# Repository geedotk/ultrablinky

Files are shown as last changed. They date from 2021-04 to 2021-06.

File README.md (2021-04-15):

# Ultrablinky Hardware

Ultrablinky is a strobelight/stroboscope that has multiple blink modes and can be triggered by different stimuli. If blinking an LED is the "Hello, world!" of the hardware/firmware world, Ultrablinky is the equivalent of shouting "HELLO, WORLD!"

## Use cases:
- Camera strobe, where a set number of flashes are triggered by motion
- Continuous flashing, because you know you want to pretend like you're at a rave
- Flashing synchronized with sound, because you still want to pretend you're at a rave, but you got tired of the asynchronous flashing
- Continuous flashing to freeze repetitive motion. Although it will look like the motion is stopped, don't be an idiot and stick your fingers in it, because it will hurt.
- Do other cool stuff that hasn't been thought of yet.

## Hardware
The "blinky" in the Ultrablinky is a 100W COB LED. This LED has forward voltage Vf of
30V-36V with a current of 3.5A.

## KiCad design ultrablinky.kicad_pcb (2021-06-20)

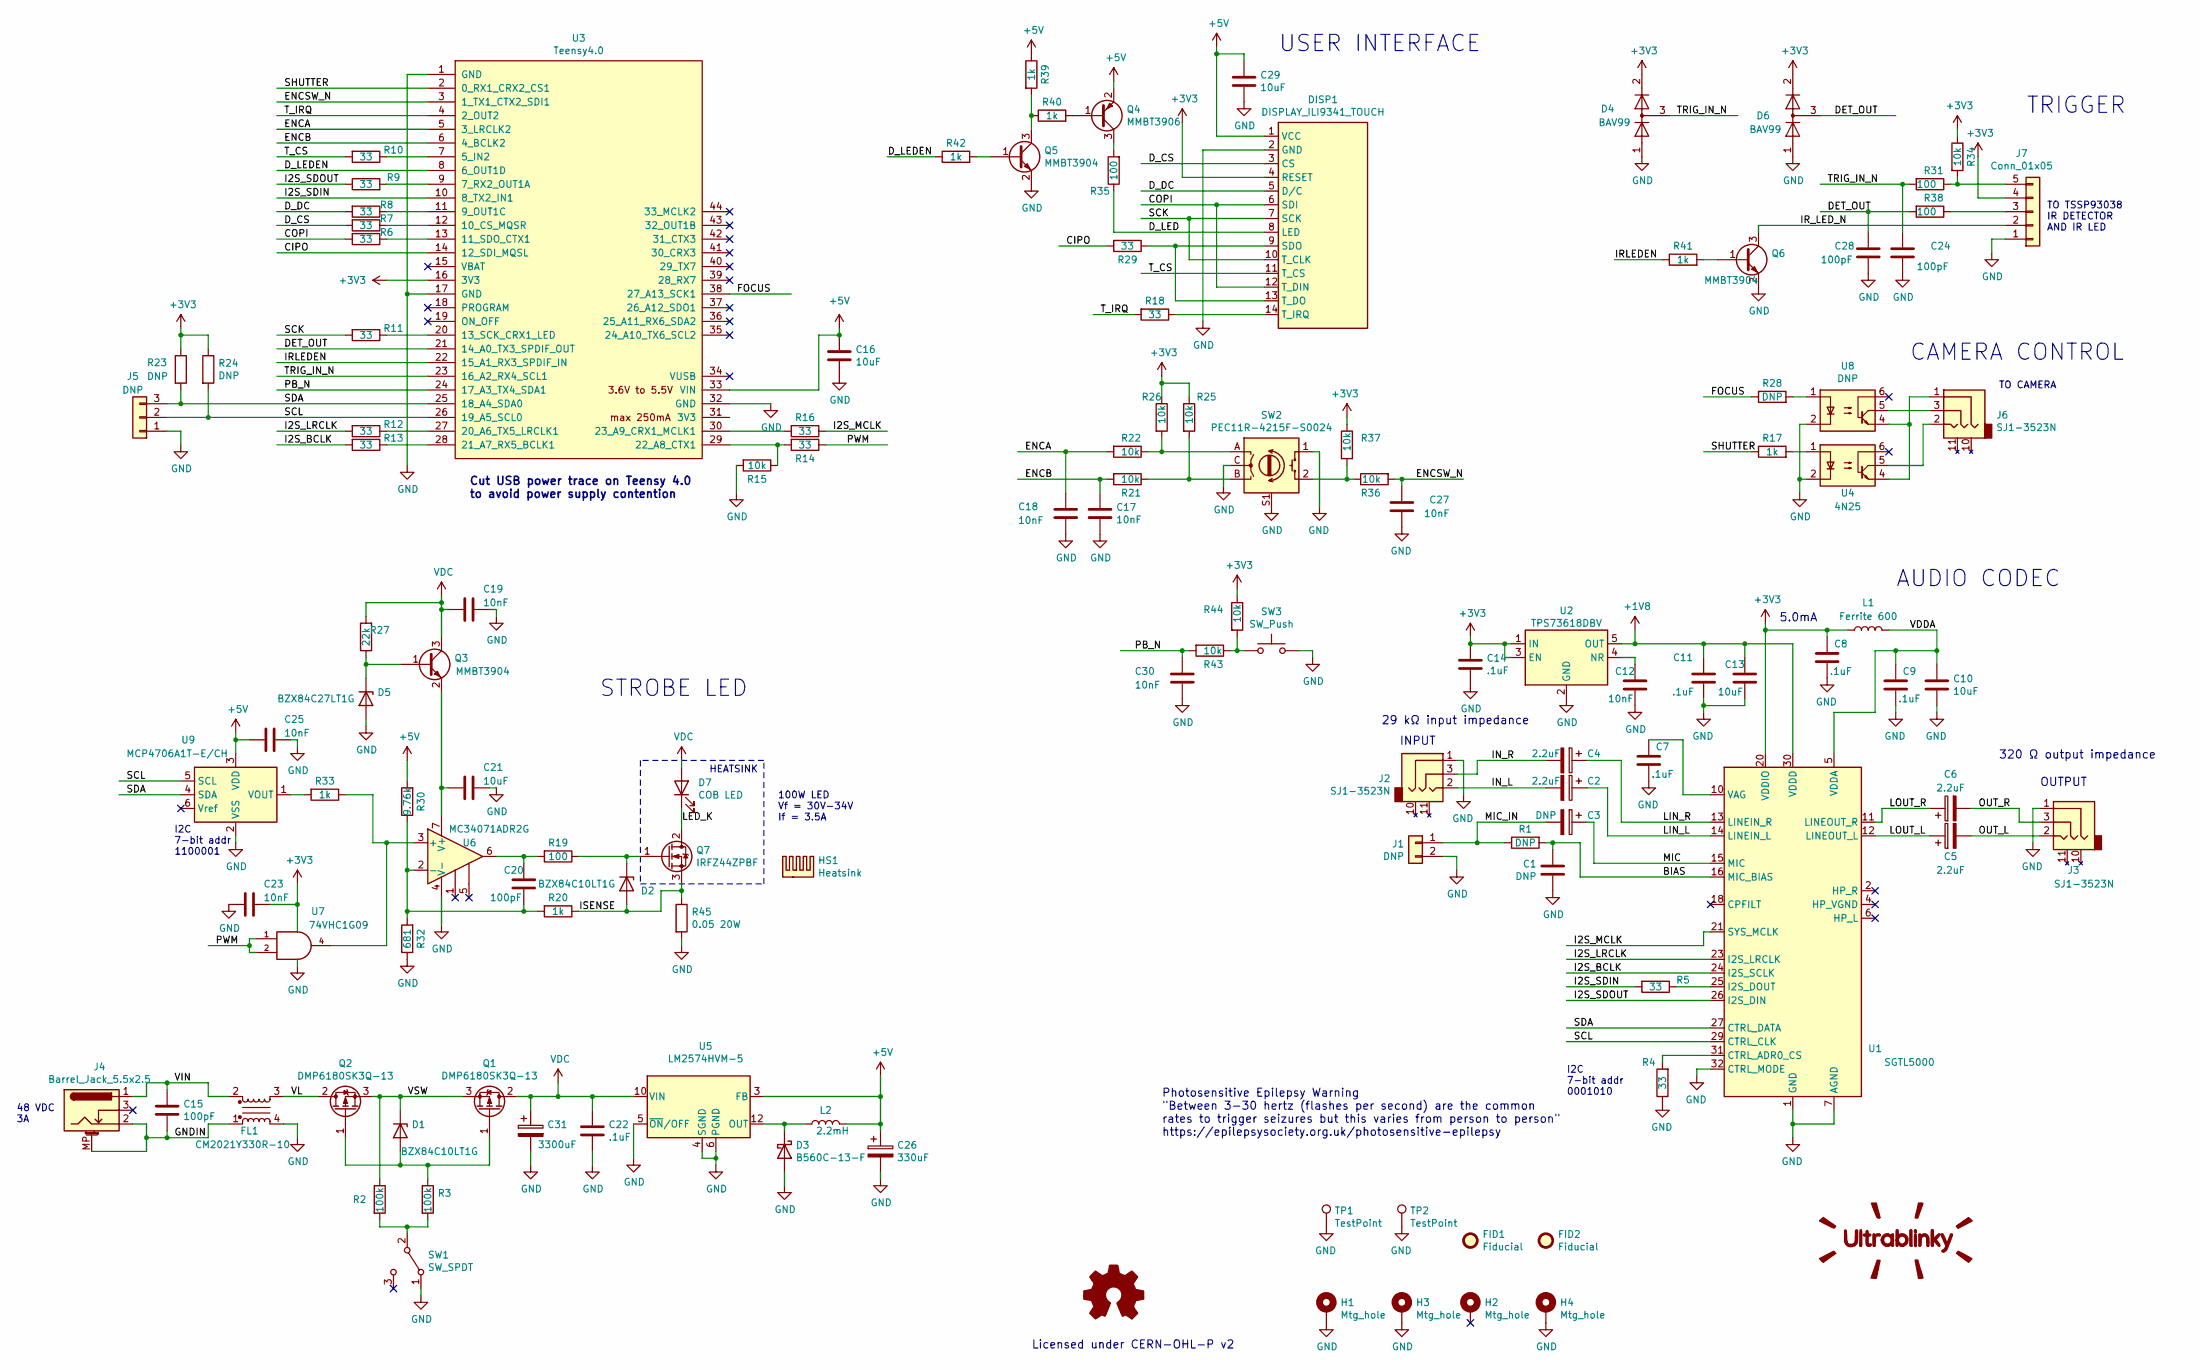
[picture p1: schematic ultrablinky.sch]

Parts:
C1: DNP; C_1206_3216Metric
C2, C4, C5, C6: 2.2uF; CP_Elec_4x5.7
C3: DNP; CP_Elec_4x5.7
C7, C8, C9, C11, C14, C22: .1uF; R_0805_2012Metric
C10, C13, C16, C21, C29: 10uF; C_1206_3216Metric
C12, C17, C18, C19, C23, C25, C27, C30: 10nF; C_0805_2012Metric
C15, C20, C24, C28: 100pF; C_0805_2012Metric
C26: 330uF; CP_Elec_8x10
C31: 3300uF; CP_Radial_L40.0mm_D20.0mm_P7.50mm_Horizontal
D1, D2: BZX84C10LT1G; D_SOT-23_ANK
D3: B560C-13-F; D_SMC
D4, D6: BAV99; SOT-23
D5: BZX84C27LT1G; D_SOT-23_ANK
D7: COB LED; LED_COB_100W
DISP1: DISPLAY_ILI9341_TOUCH
FID1, FID2: Fiducial; Fiducial_1mm_Mask2mm
FL1: CM2021Y330R-10; CM2021Y330R10
H1, H2, H3, H4: Mtg_hole; MountingHole_3.2mm_M3_DIN965_Pad
HS1: Heatsink; Heatsink_70x70mm_ATS-CPX070070025-136-C2-R0
J1: DNP; PinHeader_1x02_P2.54mm_Vertical
J2, J3, J6: SJ1-3523N; SJ13523N1_TRS_Jack
J4: Barrel_Jack_5.5x2.5; CUI_PJ-079BH
J5: DNP; PinHeader_1x03_P2.54mm_Vertical
J7: Conn_01x05; Molex_Mini-Fit_Jr_39-30-3055_1x05_P4.20mm_Horizontal
L1: Ferrite 600; L_0805_2012Metric
L2: 2.2mH; L_12x12mm_H10mm
LOGO1: Ultrablinky_logo; logo_ultrablinky
LOGO2: Logo_Open_Hardware_Small; OSHW-Logo2_9.8x8mm_SilkScreen
Q1, Q2: DMP6180SK3Q-13; TO-252-2
Q3, Q5, Q6: MMBT3904; SOT-23
Q4: MMBT3906; SOT-23
Q7: IRFZ44ZPBF; TO-220-3_Horizontal_TabDown
R1, R23, R24, R28: DNP; R_0805_2012Metric
R2, R3: 100k; R_0805_2012Metric
R4, R5, R6, R7, R8, R9, R10, R11, R12, R13, R14, R16, R18, R29: 33; R_0805_2012Metric
R15, R21, R22, R25, R26, R34, R36, R37, R43, R44: 10k; R_0805_2012Metric
R17, R20, R33, R39, R40, R41, R42: 1k; R_0805_2012Metric
R19, R31, R35, R38: 100; R_0805_2012Metric
R27: 22k; R_0805_2012Metric
R30: 9.76k; R_0805_2012Metric
R32: 681; R_0805_2012Metric
R45: 0.05 20W; TO-220-2_Horizontal_TabDown
SW1: SW_SPDT; SW_EG1213
SW2: PEC11R-4215F-S0024
SW3: SW_Push; SW_PUSH_6mm_H17mm
TP1, TP2: TestPoint; TestPoint_Keystone_5006
U1: SGTL5000; QFN-32-1EP_5x5mm_P0.5mm_EP3.6x3.6mm
U2: TPS73618DBV; SOT-23-5
U3: Teensy4.0; Teensy40
U4: 4N25; 4N25_OPTOCOUPLER_SMD
U5: LM2574HVM-5; SOIC-14W_7.5x9mm_P1.27mm
U6: MC34071ADR2G; SOIC-8_3.9x4.9mm_P1.27mm
U7: 74VHC1G09; SOT-353_SC-70-5_Handsoldering
U8: DNP; 4N25_OPTOCOUPLER_SMD
U9: MCP4706A1T-E/CH; SOT-23-6

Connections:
+1V8: C11.1, C13.1, U1.30 (VDDD), U2.5 (OUT)
+3V3: C8.1, C14.1, C23.1, D4.2 (A), D6.2 (A), DISP1.4 (RESET), J7.4, L1.1, R23.1, R24.1, R25.1, R26.1, R34.1, R37.1, R44.1, U1.20 (VDDIO), U2.1 (IN), U2.3 (EN), U3.16 (3V3), U7.5 (VCC)
+5V: C16.1, C25.2, C26.1, C29.1, DISP1.1 (VCC), L2.2, Q4.2 (E), R30.2, R39.1, U3.33 (VIN), U5.3 (FB), U9.3 (VDD)
/BIAS: C1.1, R1.2, U1.16 (MIC_BIAS)
/CIPO: R29.2, U3.14 (12_SDI_MQSL)
/COPI: DISP1.6 (SDI), DISP1.12 (T_DIN), R6.2
/DET_OUT: C28.1, D6.3 (K), R38.2, U3.21 (14_A0_TX3_SPDIF_OUT)
/D_CS: DISP1.3 (CS), R7.2
/D_DC: DISP1.5 (D/C), R8.2
/D_LED: DISP1.8 (LED), R35.1
/D_LEDEN: R42.1, U3.8 (6_OUT1D)
/ENCA: C18.1, R22.2, U3.5 (3_LRCLK2)
/ENCB: C17.1, R21.2, U3.6 (4_BCLK2)
/ENCSW_N: C27.1, R36.2, U3.3 (1_TX1_CTX2_SDI1)
/FOCUS: R28.1, U3.38 (27_A13_SCK1)
/GNDIN: C15.2, FL1.1, J4.2, J4.MP (MountPin)
/I2S_BCLK: R13.2, U1.24 (I2S_SCLK)
/I2S_LRCLK: R12.2, U1.23 (I2S_LRCLK)
/I2S_MCLK: R16.1, U1.21 (SYS_MCLK)
/I2S_SDIN: R5.2, U3.10 (8_TX2_IN1)
/I2S_SDOUT: R9.1, U1.26 (I2S_DIN)
/IN_L: C2.2, J2.2
/IN_R: C4.2, J2.3
/IRLEDEN: R41.1, U3.22 (15_A1_RX3_SPDIF_IN)
/IR_LED_N: J7.2, Q6.3 (C)
/ISENSE: D2.2 (A), Q7.3 (S), R20.1, R45.1
/LED_K: D7.1 (K), Q7.2 (D)
/LIN_L: C2.1, U1.14 (LINEIN_L)
/LIN_R: C4.1, U1.13 (LINEIN_R)
/LOUT_L: C5.1, U1.12 (LINEOUT_L)
/LOUT_R: C6.1, U1.11 (LINEOUT_R)
/MIC: C3.1, U1.15 (MIC)
/MIC_IN: C3.2, J1.1, R1.1
/OUT_L: C5.2, J3.2
/OUT_R: C6.2, J3.3
/PB_N: C30.1, R43.2, U3.24 (17_A3_TX4_SDA1)
/PWM: R14.1, U7.1, U7.2
/SCK: DISP1.7 (SCK), DISP1.10 (T_CLK), R11.2
/SCL: J5.2, R24.2, U1.29 (CTRL_CLK), U3.26 (19_A5_SCL0), U9.5 (SCL)
/SDA: J5.3, R23.2, U1.27 (CTRL_DATA), U3.25 (18_A4_SDA0), U9.4 (SDA)
/SHUTTER: R17.1, U3.2 (0_RX1_CRX2_CS1)
/TRIG_IN_N: C24.1, D4.3 (K), R31.2, U3.23 (16_A2_RX4_SCL1)
/T_CS: DISP1.11 (T_CS), R10.2
/T_IRQ: R18.2, U3.4 (2_OUT2)
/VDDA: C9.1, C10.1, L1.2, U1.5 (VDDA)
/VIN: C15.1, FL1.2, J4.1
/VL: FL1.3, Q2.2 (D)
/VSW: D1.1 (K), Q1.3 (S), Q2.3 (S), R2.1
GND: C1.2, C7.2, C8.2, C9.2, C10.2, C11.2, C12.2, C13.2, C14.2, C16.2, C17.2, C18.2, C19.1, C21.1, C22.2, C23.2, C24.2, C25.1, C26.2, C27.2, C28.2, C29.2, C30.2, C31.2, D3.2 (A), D4.1 (K), D5.2 (A), D6.1 (K), DISP1.2 (GND), FL1.4, H1.1, H3.1, H4.1, J1.2, J2.1, J3.1, J5.1, J7.1, Q5.2 (E), Q6.2 (E), R4.1, R15.2, R32.1, R45.2, SW1.1 (A), SW2.1, SW2.C, SW2.S1, SW2.S2, SW3.2, TP1.1, TP2.1, U1.1 (GND), U1.3 (GND), U1.7 (AGND), U1.32 (CTRL_MODE), U1.33 (GND), U2.2 (GND), U3.1 (GND), U3.17 (GND), U3.32 (GND), U4.2, U5.1 (NC), U5.2 (NC), U5.4 (SGND), U5.5 (~ON~/OFF), U5.6 (PGND), U5.7 (NC), U5.8 (NC), U5.9 (NC), U5.11 (NC), U5.13 (NC), U5.14 (NC), U6.4 (V-), U7.3 (GND), U8.2, U9.2 (VSS)
unnamed: C7.1, U1.10 (VAG)
unnamed: C12.1, U2.4 (NR)
unnamed: C20.1, R19.2, U6.6
unnamed: C20.2, R20.2, R30.1, R32.2, U6.2 (-)
unnamed: C21.2, Q3.2 (E), U6.7 (V+)
unnamed: D1.2 (A), Q1.1 (G), Q2.1 (G), R3.1
unnamed: D2.1 (K), Q7.1 (G), R19.1
unnamed: D3.1 (K), L2.1, U5.12 (OUT)
unnamed: D5.1 (K), Q3.1 (B), R27.1
unnamed: DISP1.9 (SDO), DISP1.13 (T_DO), R29.1
unnamed: DISP1.14 (T_IRQ), R18.1
unnamed: J6.1, U4.4, U8.4
unnamed: J6.2, U4.5
unnamed: J6.3, U8.5
unnamed: J7.3, R38.1
unnamed: J7.5, R31.1, R34.2
unnamed: Q4.1 (B), R40.2
unnamed: Q4.3 (C), R35.2
unnamed: Q5.1 (B), R42.2
unnamed: Q5.3 (C), R39.2, R40.1
unnamed: Q6.1 (B), R41.2
unnamed: R2.2, R3.2, SW1.2 (B)
unnamed: R4.2, U1.31 (CTRL_ADR0_CS)
unnamed: R5.1, U1.25 (I2S_DOUT)
unnamed: R6.1, U3.13 (11_SDO_CTX1)
unnamed: R7.1, U3.12 (10_CS_MQSR)
unnamed: R8.1, U3.11 (9_OUT1C)
unnamed: R9.2, U3.9 (7_RX2_OUT1A)
unnamed: R10.1, U3.7 (5_IN2)
unnamed: R11.1, U3.20 (13_SCK_CRX1_LED)
unnamed: R12.1, U3.27 (20_A6_TX5_LRCLK1)
unnamed: R13.1, U3.28 (21_A7_RX5_BCLK1)
unnamed: R14.2, R15.1, U3.29 (22_A8_CTX1)
unnamed: R16.2, U3.30 (23_A9_CRX1_MCLK1)
unnamed: R17.2, U4.1
unnamed: R21.1, R25.2, SW2.B
unnamed: R22.1, R26.2, SW2.A
unnamed: R28.2, U8.1
unnamed: R33.1, U6.3 (+), U7.4
unnamed: R33.2, U9.1 (VOUT)
unnamed: R36.1, R37.2, SW2.2
unnamed: R43.1, R44.2, SW3.1
VDC: C19.2, C22.1, C31.1, D7.2 (A), Q1.2 (D), Q3.3 (C), R27.2, U5.10 (VIN)

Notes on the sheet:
HEATSINK
100W LED Vf = 30V-34V If = 3.5A
I2C 7-bit addr 1100001
48 VDC 3A
Photosensitive Epilepsy Warning "Between 3-30 hertz (flashes per second) are the common rates to trigger seizures but this varies from person to person" https://epilepsysociety.org.uk/photosensitive-epilepsy
Licensed under CERN-OHL-P v2
Cut USB power trace on Teensy 4.0 to avoid power supply contention
TO CAMERA
TO TSSP93038 IR DETECTOR AND IR LED
INPUT
OUTPUT
AUDIO CODEC
29 kΩ input impedance
320 Ω output impedance
I2C 7-bit addr 0001010
USER INTERFACE
STROBE LED
TRIGGER
CAMERA CONTROL
5.0mA

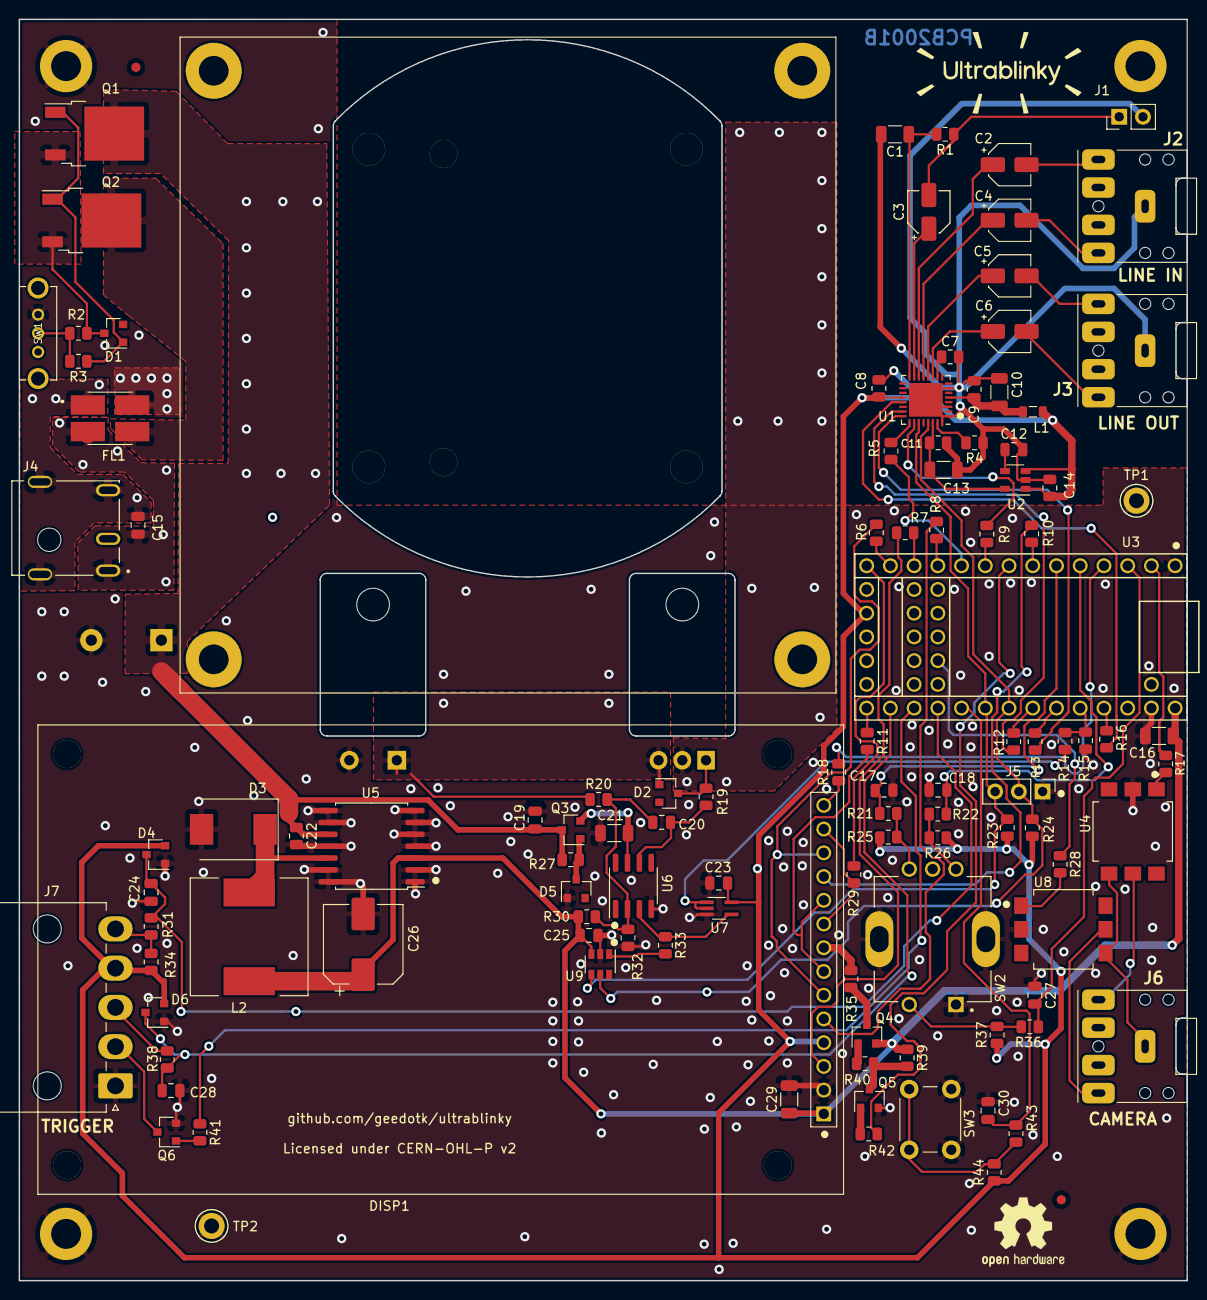
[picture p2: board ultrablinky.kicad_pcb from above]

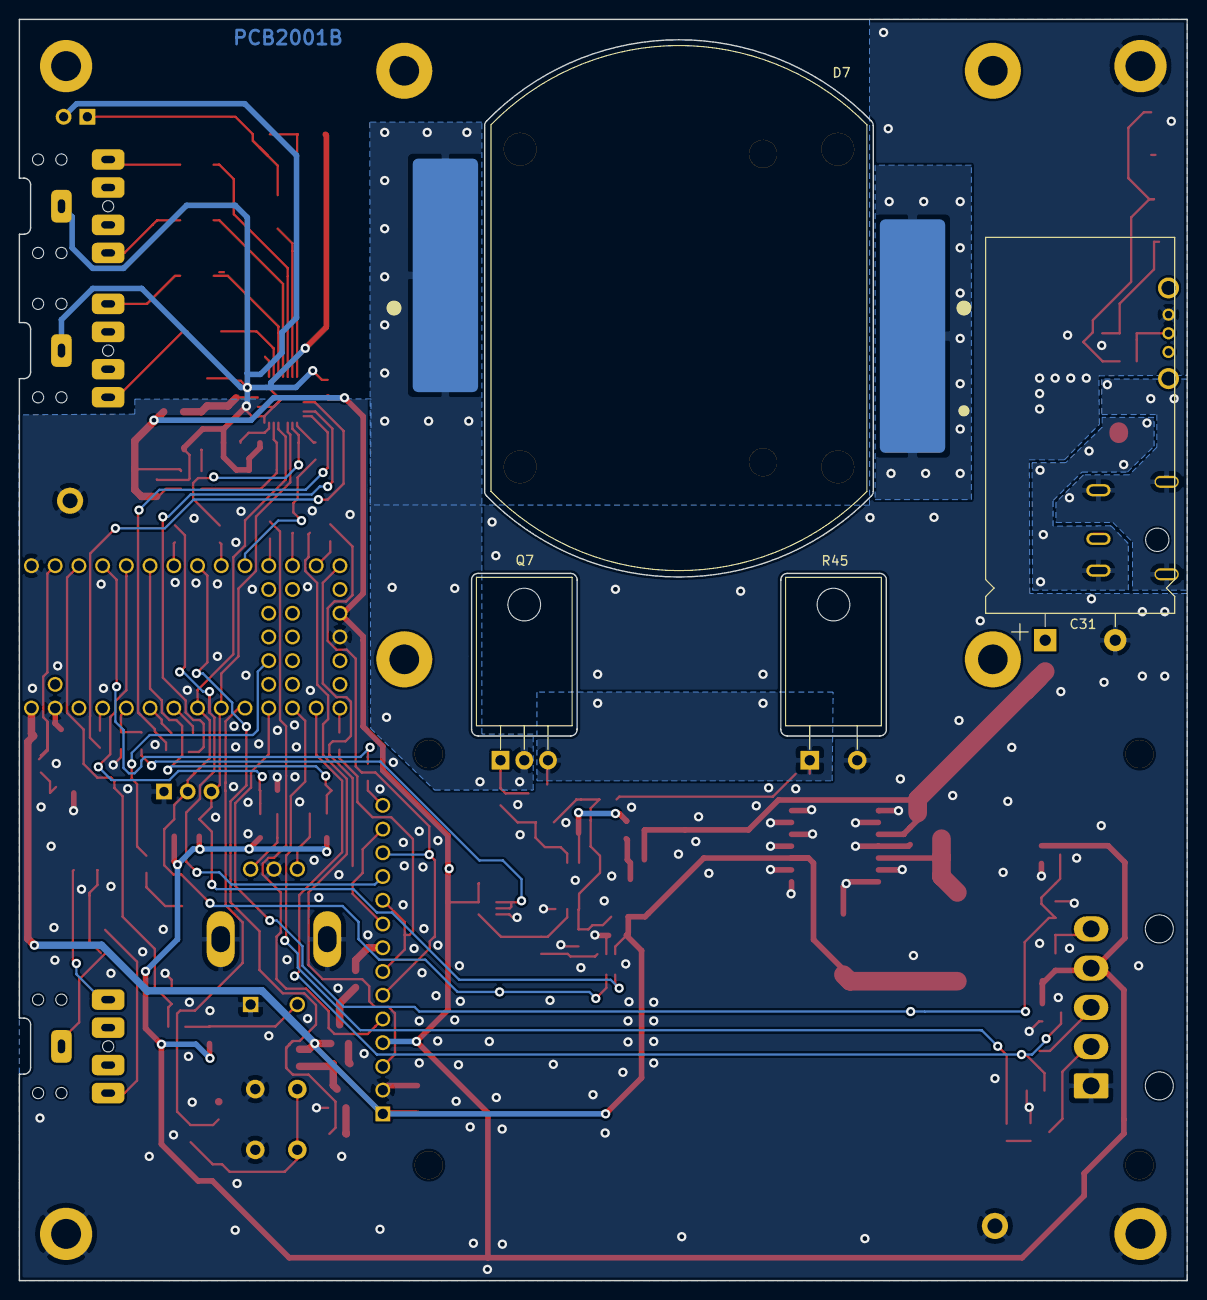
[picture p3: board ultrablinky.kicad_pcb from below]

Board: 2 copper layers, 125.0 x 135.0 mm, 124 parts (4 on the bottom side), 92 nets.

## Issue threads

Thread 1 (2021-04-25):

Open Hardware logo is illegible

geedotk, 2021-04-25:
Need to use a larger logo, or at least one with a larger font

geedotk, 2021-06-16:
Fixed on PCB2001B

Closed 2021-06-16.

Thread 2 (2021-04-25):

Q7 and R43 references overlap with board edge cut

geedotk, 2021-04-25:
The bottom part of the Q7 and R43 references are cut off by the board edge cut. Need to move them higher

geedotk, 2021-06-16:
Fixed on PCB2001B

Closed 2021-06-16.

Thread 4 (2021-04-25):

Add more prominent pin 1 markers

geedotk, 2021-04-25:
The KiCad pin 1 markers for ICs are very difficult to see. Add something (dots?) that is easier to see for hand assembly.

geedotk, 2021-07-06:
Fixed on rev B PCB

Closed 2021-07-06.

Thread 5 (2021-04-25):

Optocoupler footprint is too narrow

geedotk, 2021-04-25:
The footprint for optocouplers U4 and U7 are so narrow that the pins go all the way to edge of the pad, leaving much pad underneath the part

geedotk, 2021-06-19:
Corrected the footprint to match the suggested pattern in the data sheet

Closed 2021-06-19.

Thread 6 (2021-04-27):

Through-holes for display (DISP1) connector are too small

geedotk, 2021-04-27:
The holes on the 1x14 connector are only 0.7mm, when they should be at least 1mm. Now they are too small for a 0.025" square post. Make these larger on the next rev

geedotk, 2021-06-19:
Changed hole size to be 1.1mm

Closed 2021-06-19.

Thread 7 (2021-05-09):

I2S SDIN and SDOUT going to wrong pins of Teensy

geedotk, 2021-05-09:
I2S SDIN and SDOUT currently go to pins 7 and 8 of the Teensy footprint, when they should go to Arduino DIO pins 7 and 8 instead, which are actually pins 9 and 10 of the Teensy footprint.

geedotk, 2021-05-12:
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
Pin 7 should be swapped with pin 10. Pin 8 should be swapped with pin 9.

geedotk, 2021-06-19:
Corrected traces on rev B PCB

Closed 2021-06-19.

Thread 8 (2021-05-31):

Strobe LED stays on dimly when PWM should shut it off completely

geedotk, 2021-05-31:
The non-inverting input of the U6 op amp goes down to about 13mV when the PWM signal is high, but that's still enough for about 26mA of current to go through the COB LED.

One possible solution is to pull up the inverting input of the op amp so that it is certain to be higher than the lowest voltage on the non-inverting input.

geedotk, 2021-05-31:
Adding a 22k resistor from 5V to the inverting input of the op amp allows the LED to be turned off completely. This will be fixed in the next revision of the PCB

geedotk, 2021-06-19:
Added pull-up resistor to rev B PCB

Closed 2021-06-19.

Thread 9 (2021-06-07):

High current can cause current-sense resistor voltage more than 5V

geedotk, 2021-06-07:
The COB LED needs to be overdriven in order to be bright enough with short pulse widths. However, the 0.5-ohm resistor will have a voltage more than 5V when the current is only 10A. The current sense resistor needs to be smaller.

geedotk, 2021-06-19:
Changed resistor to 0.05 ohms on rev B PCB

Closed 2021-06-19.

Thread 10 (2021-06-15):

Disabled PWM timer defaults to the strobe LED being on

geedotk, 2021-06-15:
When the Teensy PWM timer is disabled, the output is low. Since the output goes through an NPN transistor to pull the DAC low, this means the DAC output will be high. The logic needs another inversion so that when the PWM timer is disabled low, the DAC will also be pulled low.

geedotk, 2021-06-19:
Changed NPN transistor to 74VHC1G09 gate so that no inversion takes place on rev B PCB

Closed 2021-06-19.

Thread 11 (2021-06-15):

High-current drive of the strobe LED pulls supply down

geedotk, 2021-06-15:
The strobe LED will often need much more than the 6A that the power supply can source. More capacitance will be needed to allow this to happen.

geedotk, 2021-06-19:
Added 3300uF capacitor on rev B PCB

Closed 2021-06-19.

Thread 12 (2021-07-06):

Inrush current damages the power switch MOSFET

geedotk, 2021-07-06:
On the rev B PCB, a 3300uF capacitor was added to the power rail. When the power switch is turned on, the inrush current to charge that capacitor was measured to be up to 120A for about 0.5ms, which destroys the Q1 MOSFET. The maximum continuous current for that MOSFET is 14A.

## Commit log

2021-04-15 First version of Ultrablinky strobe
    KiCad schematics and PCB (PCB2001A) for Ultrablinky strobe.
    [ultrablinky-B_Cu.gbr, ultrablinky-B_Fab.gbr, ultrablinky-B_Mask.gbr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]
2021-04-26 Changed C12 from 50V to 100V
    This was changed so that the same 10nF cap could be used in all
    locations instead of having two different 10nF parts
    [ultrablinky.sch]
2021-05-26 Corrected the I2S_SDIN and I2S_SDOUT pins
    Previously, the I2S_SDIN and I2S_SDOUT pins were connected to pins 7 and
    8 of the Teensy package. However, they should have been connected to
    Arduino digital I/O pins 7 and 8 instead. These pins are actually pins
    10 and 9 of the Teensy package. Pins 10 and 9 of the Teensy package were
    instead connected to T_CS and D_LEDEN.
    In order to fix this problem, the signals on pins 7 and 10 (I2S_SDIN and
    T_CS) were swapped. Also the signals on pins 8 and 9 (I2S_SDOUT and
    D_LEDEN) were swapped. This was done with cuts and jumper wires on
    PCB2001A. It will be fixed in etch on PCB2001B.
    [ultrablinky.sch]
2021-05-31 Improve rise/fall time
    Changed C21 from 10nF to 100pF
    [ultrablinky.sch]
2021-05-31 Fixed LED staying on when it shouldn't be
    Previously there were two times when the strobe LED stayed on when it
    was supposed to be off. First, when the system started, the PWM pin
    would float and would not turn off the LED. Secondly, the non-inverting
    input of the op amp would not go low enough to completely turn off off
    the LED.
    The startup problem was fixed by adding a 10k pull-up resistor to the
    PWM signal so that it would be high during the time before the code
    initialized that signal to be an output and actively drives it.
    The second problem was fixed by adding a 22k pull-up to 5V on the
    inverting input of the op amp. This kept the inverting input at a higher
    voltage and allowed the n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
    [ultrablinky.sch]
2021-06-01 Fixed low drive voltage for LED MOSFET
    The MC34071ADR2G op amp has a Voh that may be as low as 3.7V when
    powered with 5V, which is
    not enough to fully turn on the COB LED MOSFET. The power supply was
    changed to 36V to allow a much higher voltage.
    Also added a 10V zener across the gate and source of the COB LED MOSFET
    to avoid having the voltage exceed the maximum Vgs which is 20V.
    [ultrablinky.sch]
2021-06-05 Increased voltage from 36V to 48V
    Previously, the op amp was supplied voltage directly from the 36V power
    supply. However, this was not high enough to drive the COB LED to high
    currents. Now, the voltage has been increased to 48V, but this
    necessitated regulating the voltage to the MC34071A because it cannot
    handle 48V.
    [ultrablinky.sch]
2021-06-06 Increase C22 to 22uF
    C22 was changed to 22uF to provide better filter of the op amp power
    supply
    [ultrablinky.sch]
2021-06-07 Changed current-sense resistor to allow higher current
    The current-sense resistor R43 was changed from 0.5-ohm to 0.05-ohm to
    allow more current while keeping the voltage across the resistor lower.
    Additionally, a pull-down resistor was added to the op amp non-inverting
    input so that a current-sense voltage of 0V to 12V gets converted to a
    range of 0.2V to 4.9V at the non-inverting input of the op amp.
    Additionally, the voltage divider on the Vref input of the MCP4706A DAC
    was removed because the VDD power input will be used as the reference
    instead.
    [ultrablinky.sch]
2021-06-15 Fixed inverted logic of PWM enable
    The NPN transistor has now been replaced with a 74VHC1G09 open-drain
    driver. This means that when the PWM output of the Teensy is low, the
    DAC will also be low instead of being inverted
    [ultrablinky.sch]
2021-06-16 Increased bus cap to 3300uF
    The bus capacitance needs to be high enough to allow for short pulses of
    much higher current than the power supply can put out so a large value
    is needed
    [ultrablinky.sch]
2021-06-16 Changed film caps to electrolytic
    The film caps in the audio path were changed to electrolytic in order to
    bring down the cost and have better availability
    [ultrablinky.sch]
2021-06-18 Added Ultrablinky logo symbol and footprint
    [ultrablinky.kicad_pcb]
2021-06-19 Updated PCB with schematic changes
    The rev B PCB now has the I2S SDIN and I2S SDOUT pins corrected. The
    power supply has been changed to 48V. The PWM logic has been inverted.
    The bus capacitance has been increased to 3300uF. The capacitors in the
    audio path have been changed from film caps to electrolytic. The
    Ultrablinky logo has been added.
    [ultrablinky.kicad_pcb, ultrablinky.sch]
2021-06-19 Corrected 4N25 footprints
    Previously the 4N25 footprints were too narrow for the pins.
    [ultrablinky.kicad_pcb, ultrablinky.sch]
2021-06-19 Added two additional bypass caps
    The voltage regulator for the op amp and the 74VHC1G09 did not have
    bypass caps previously
    [ultrablinky.kicad_pcb, ultrablinky.sch]
2021-06-19 Eliminated 5v-3.3v regulator
    The Teensy 4.0 has a 3.3V pin that can supply up to 250mA, so that is
    now the source for 3.3V.
    [ultrablinky.kicad_pcb, ultrablinky.sch]
2021-06-20 General cleanup and generate Gerbers
    [ultrablinky-B_Cu.gbr, ultrablinky-B_Fab.gbr, ultrablinky-B_Mask.gbr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]
2021-06-20 Changed 22uF cap to 10uF to reduce BOM cost
    [ultrablinky-B_Cu.gbr, ultrablinky-B_Fab.gbr, ultrablinky-B_Mask.gbr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]
2021-06-20 Changed DAC part to change I2C address
    The DAC was changed from MCP4706A1 to MCP4706A0. This is the same
    functionality, but the I2C address was changed from 1100001 to 1100000.
    This part seems to have somewhat better availability.
    [ultrablinky.sch]
